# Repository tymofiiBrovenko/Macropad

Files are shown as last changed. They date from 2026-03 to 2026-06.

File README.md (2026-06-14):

# LaTeX-PAD: Custom Macropad for Math & Science (RP2040)



This is a custom 15-key macropad with a rotary encoder. I built it mainly to speed up writing math formulas in LaTeX. It runs on a Seeeduino XIAO RP2040 using custom QMK firmware.

I designed this project to make my life easier when typing complex equations. It combines a regular numpad with some really handy LaTeX macros.

## Key Features

* **15 Cherry MX-style keys** wired in a 4x4 ortholinear matrix.
* **1 Rotary Encoder (EC11)** with a push-button switch.
* **Smart Cursor Navigation:** The macros do the boring work for you. If you paste a command like `\frac{}{}`, the cursor automatically jumps back inside the first set of brackets so you can start typing right away.
* **Seeeduino XIAO RP2040:** Has more than enough memory and pins for complex QMK setups.

## Hardware & Enclosure

### Case Design
I designed the enclosure from scratch in Fusion 360 to securely hold the PCB, switches, and the microcontroller together. 
* *Optional: The case is 3D printed in [PLA/PETG] and held together with [M3 screws].*

<div align="center">
  CAD render 1
  CAD render 2
" />
</div>

### PCB
<div align="center">
  PCB Front
  PCB Back
</div>

> **Note:** The footprint library in the schematic might show SAMD21 pinouts (D0, D1, etc.). Just ignore that — the actual hardware uses the XIAO RP2040, and the QMK firmware is mapped to the correct RP2040 pins (GP26, GP6, etc.).

### Logik
<div align="center">
  
</div>

## Firmware Details

The macropad runs on QMK Firmware to handle matrix scanning, the encoder, and all the custom macros.

### Keymap Layers
* **Base Layer (`_NUMPAD`):** Works just like a standard numpad. It also has a dedicated layer-modifier key.
* **LaTeX Layer (`_LATEX`):** Hold the modifier key to access 14 of the most common LaTeX commands (`\frac{}{}`, `\sqrt{}`, `\sum_{}^{}`, `\int_{}^{}`, etc.).

### Rotary Encoder
* **Rotate Left/Right:** Moves the text cursor left or right. It's really useful for tweaking long equations without touching your mouse.
* **Press:** Acts as a standard Left Mouse Button click.

## Bill of Materials (BOM)

If you want to build one yourself, here's what you need:
* 1x Seeeduino XIAO RP2040
* 15x Cherry MX-compatible switches (e.g., Gateron Red)
* 1x EC11 Rotary Encoder
* 15x 1N4148 Diodes
* Custom PCB (Gerber files are in the `hardware/` folder)
* 3D Printed case parts

## How to Build & Flash

1. **Hardware:** Get the PCB fabricated using the Gerber files from the `hardware/` folder. Solder the diodes, switches, encoder, and the XIAO RP2040.
2. **Firmware:** * Set up your local QMK environment.
   * Drop the firmware folder from this repo into your `qmk_firmware/keyboards/` directory.
   * Compile and flash the board (e.g., run `qmk flash -kb latex_pad -km default`).

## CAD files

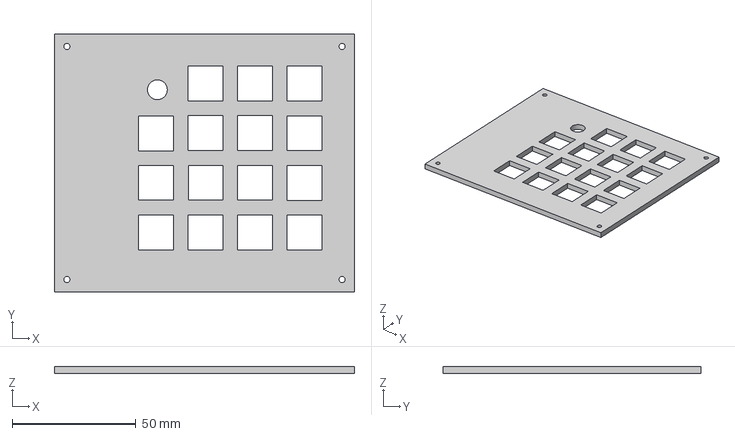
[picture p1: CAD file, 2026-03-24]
production/top.step
121.0 x 104.0 x 3.00 mm

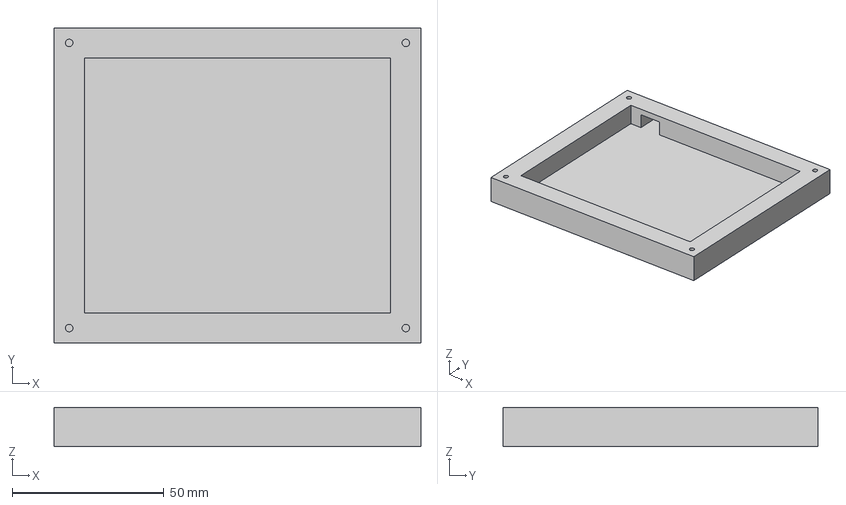
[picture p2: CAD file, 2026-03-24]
production/bottom.step
121.0 x 104.0 x 13.0 mm

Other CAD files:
cad/LATEXPAD123456.f3z

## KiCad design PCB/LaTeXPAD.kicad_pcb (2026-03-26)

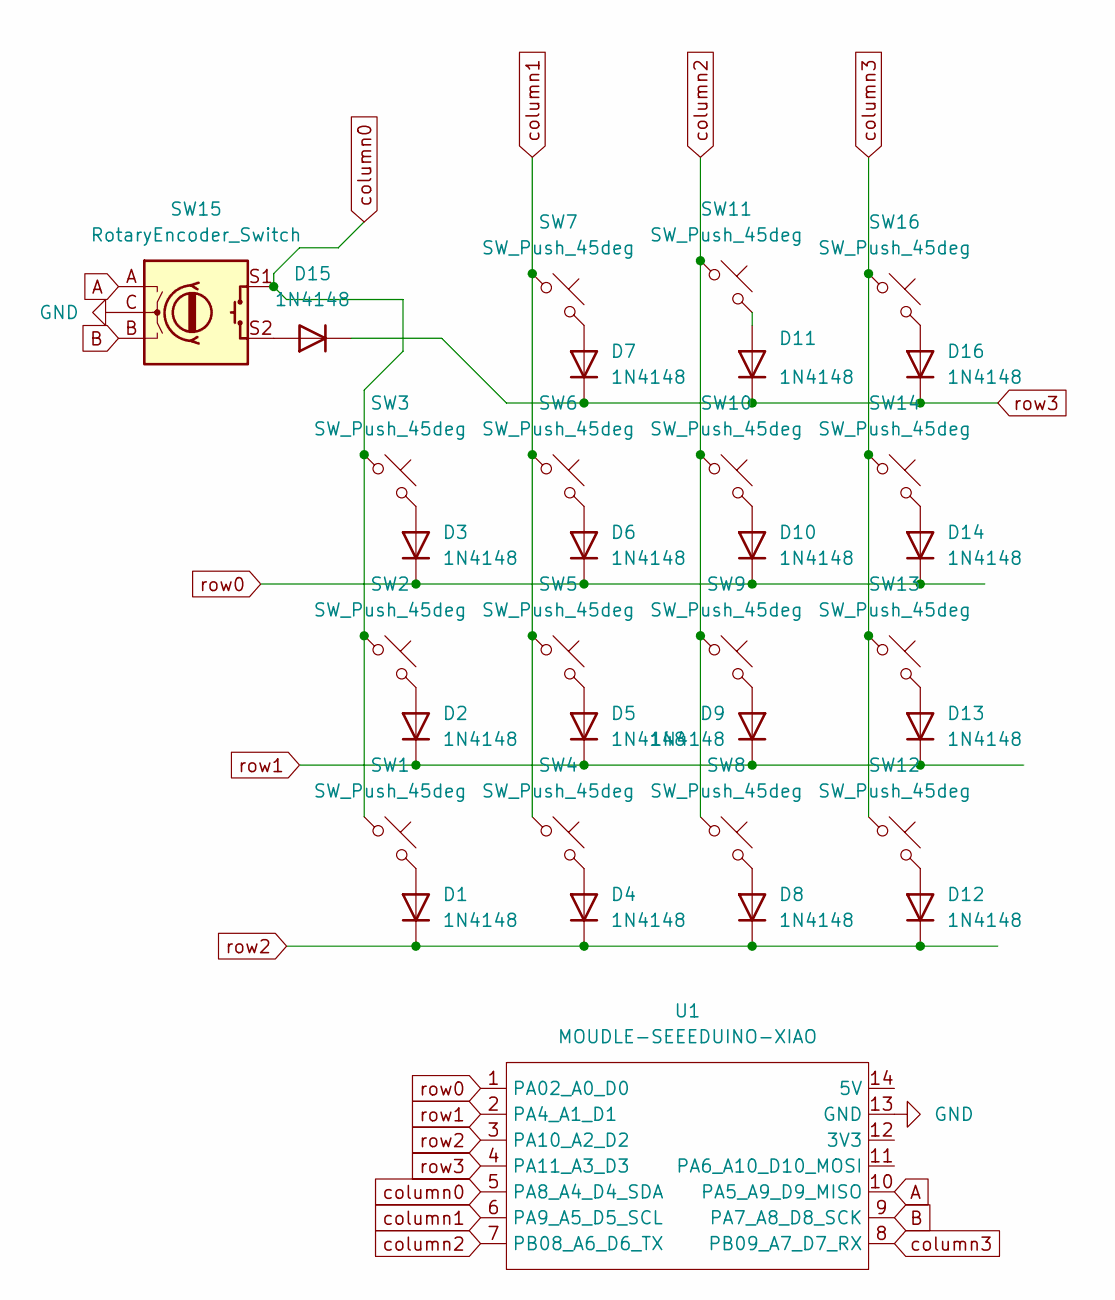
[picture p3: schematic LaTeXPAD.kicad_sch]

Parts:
D1, D2, D3, D4, D5, D6, D7, D8, D9, D10, D11, D12, D13, D14, D15, D16: 1N4148; D_DO-35_SOD27_P7.62mm_Horizontal
SW1, SW2, SW3, SW4, SW5, SW6, SW7, SW8, SW9, SW10, SW11, SW12, SW13, SW14, SW16: SW_Push_45deg; SW_Cherry_MX_1.00u_PCB
SW15: RotaryEncoder_Switch; RotaryEncoder_Alps_EC11E-Switch_Vertical_H20mm
U1: MOUDLE-SEEEDUINO-XIAO; XIAO-Generic-Hybrid-14P-2.54-21X17.8MM

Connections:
A: SW15.A, U1.10 (PA5_A9_D9_MISO)
B: SW15.B, U1.9 (PA7_A8_D8_SCK)
GND: SW15.C, U1.13 (GND)
unnamed: D1.2 (A), SW1.2
unnamed: D2.2 (A), SW2.2
unnamed: D3.2 (A), SW3.2
unnamed: D4.2 (A), SW4.2
unnamed: D5.2 (A), SW5.2
unnamed: D6.2 (A), SW6.2
unnamed: D7.2 (A), SW7.2
unnamed: D8.2 (A), SW8.2
unnamed: D9.2 (A), SW9.2
unnamed: D10.2 (A), SW10.2
unnamed: D11.2 (A), SW11.2
unnamed: D12.2 (A), SW12.2
unnamed: D13.2 (A), SW13.2
unnamed: D14.2 (A), SW14.2
unnamed: D15.2 (A), SW15.S2
unnamed: D16.2 (A), SW16.2
column0: SW1.1, SW2.1, SW3.1, SW15.S1, U1.5 (PA8_A4_D4_SDA)
column1: SW4.1, SW5.1, SW6.1, SW7.1, U1.6 (PA9_A5_D5_SCL)
column2: SW8.1, SW9.1, SW10.1, SW11.1, U1.7 (PB08_A6_D6_TX)
column3: SW12.1, SW13.1, SW14.1, SW16.1, U1.8 (PB09_A7_D7_RX)
row0: D3.1 (K), D6.1 (K), D10.1 (K), D14.1 (K), U1.1 (PA02_A0_D0)
row1: D2.1 (K), D5.1 (K), D9.1 (K), D13.1 (K), U1.2 (PA4_A1_D1)
row2: D1.1 (K), D4.1 (K), D8.1 (K), D12.1 (K), U1.3 (PA10_A2_D2)
row3: D7.1 (K), D11.1 (K), D15.1 (K), D16.1 (K), U1.4 (PA11_A3_D3)

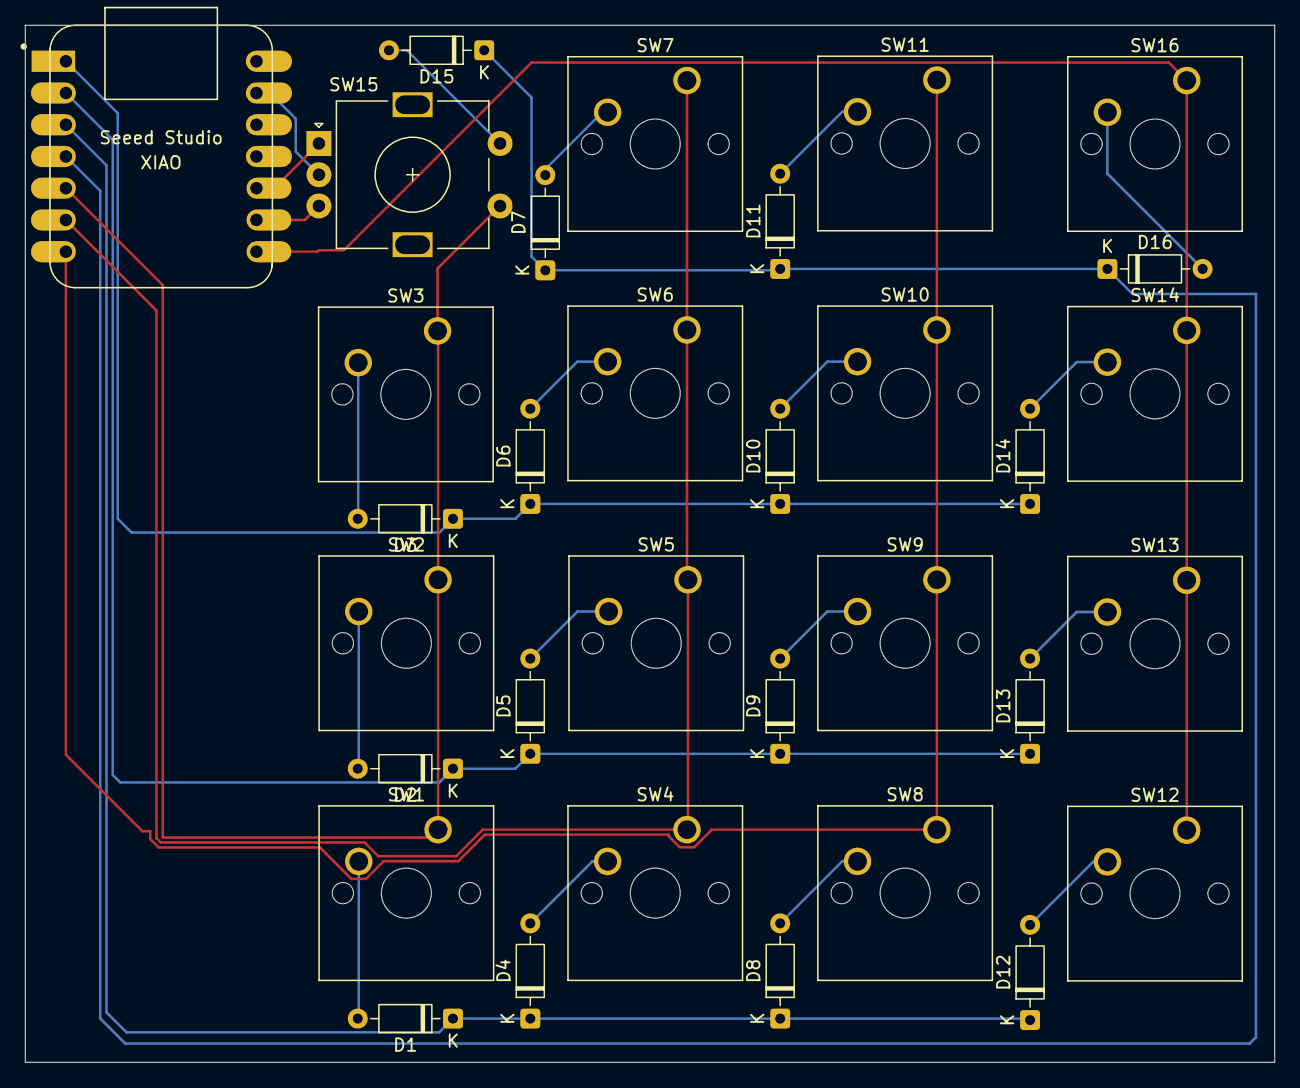
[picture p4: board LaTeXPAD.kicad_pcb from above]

Board: 2 copper layers, 100.0 x 83.0 mm, 33 parts (0 on the bottom side), 27 nets.

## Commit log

2026-03-24 Enhance README with project details and specifications
    Expanded README to include detailed project description, features, CAD model, PCB design, firmware overview, and BOM.
2026-06-14 Fix CAD software name in Readme2.md
